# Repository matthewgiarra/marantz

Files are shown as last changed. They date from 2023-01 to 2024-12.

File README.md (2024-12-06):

# marantz
Knockoffs of old Marantz stereos

# Actual content
[P700 Pre-amp board](https://github.com/matthewgiarra/marantz/tree/main/2225/PE01) with schematics, PCB layout, renders, gerber files, and photos of the completed board. 

[Confluence page](https://matthewgiarra.atlassian.net/wiki/spaces/marantz/pages/33577/Gesundheit+Model+82+Stereophonic+Receiver+Requirements) (design concepts, system requirements, etc.)

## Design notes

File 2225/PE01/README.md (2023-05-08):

# Marantz 2225 Pre-Tone Amplifier PE-01 (pre-amp)
## Overview
This project recreates (i.e., knocks off) the [Marantz 2225](https://classicreceivers.com/marantz-2225) pre-tone amplifier (PE-01), as specified in the [Marantz 2225L service manual](https://www.manualslib.com/manual/907153/Marantz-2225l.html), using modern and readily-available components. Our custom board is designed to function as a drop-in replacement for the original device. We [selected components](https://docs.google.com/spreadsheets/d/1S8Fiy-nARGqUnUXXbVScigvOsDpP3ZsTfdl-bGImHVc/edit?usp=sharing) that meet or exceed the specifications from the service manual, which were experimentally verified by measuring values of components sourced from a vintage PE-01. When discrepancies were discovered between the service manual's component specifications and physical measurements of vintage components, we prioritized the physical measurements. The PCB layout was modified as necessary to accommodate the physical dimensions of our chosen components, and uses a four-layer PCB rather than the single layer of the original product. We used KiCad for design, and validated functionality via SPICE simulation prior to manufacturing. Quantitative characterization of the physical prototype is still in progress, but the initial subjective impression is that it sounds pretty good. 

## Components
The bill of materials/components list is [here](https://docs.google.com/spreadsheets/d/1S8Fiy-nARGqUnUXXbVScigvOsDpP3ZsTfdl-bGImHVc/edit?usp=sharing).

## KiCad renders 
2225_PE01_layout
2225_PE01_front_03
2225_PE01_back_01
2225_PE01_front_02

## Prototype board (V1.0, March 2023)
marantz_2225_PE01_tone_board_replica_v1 0

## Original PCB
PE01_front
PE01_back

## Schematic and Layout (from [Marantz 2225L service manual](https://www.manualslib.com/manual/907153/Marantz-2225l.html))
PE01_layout
PE01_schematic

## Notes
- CE21 and CE22 should be 3.3µF, not 33µF as they're listed in the service manual.
- CE23 and CE24 are biopolar capacitors, which the service manual does not appear to indicate. 
- The first prototype board substituted the specified 7.5K resistors RE13 and RE14 with 4.7K 1% components. The reason for the substitution was to mitigate clipping observed at higher volume levels (i.e., lower input attenuation) of aux input from a Macbook headphone jack, which was about 1.5VPP.

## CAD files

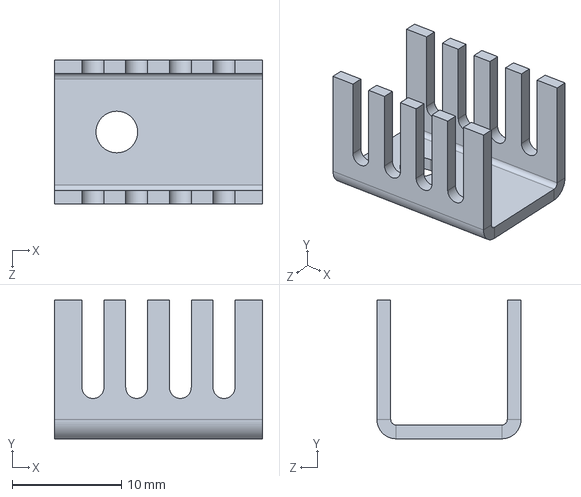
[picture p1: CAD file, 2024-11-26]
2225/P800/3dmodels/heatsink_577202B00000.STEP
19.1 x 12.7 x 13.2 mm

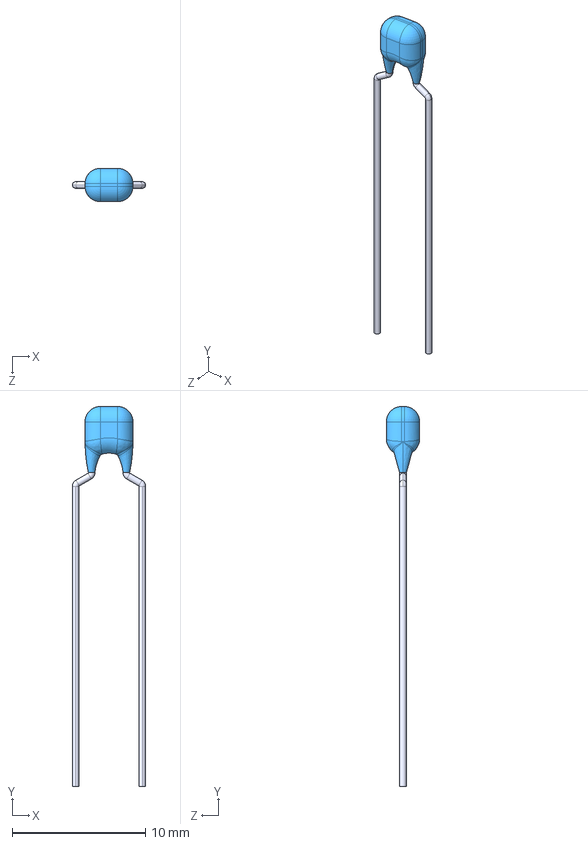
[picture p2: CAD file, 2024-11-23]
2225/P800/3dmodels/cap_ceramic_RCER71H473K0M1H03A.step
5.50 x 28.5 x 2.50 mm

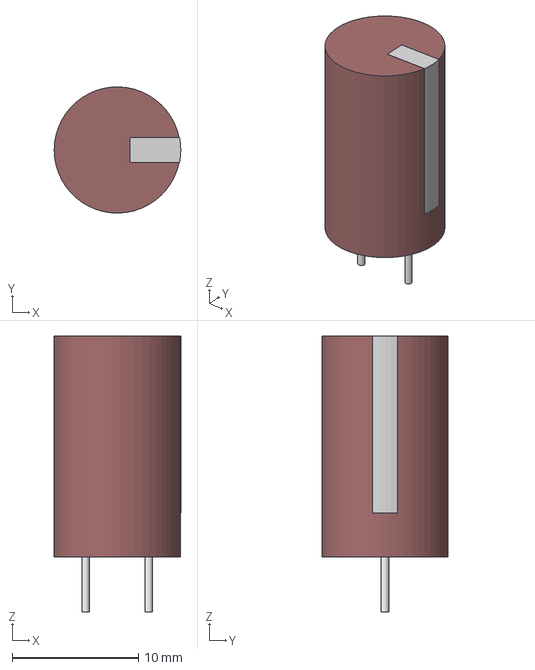
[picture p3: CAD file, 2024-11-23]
2225/P800/3dmodels/cap_electrolytic_UFG1H101MPM1TD.step
10.0 x 10.0 x 21.9 mm

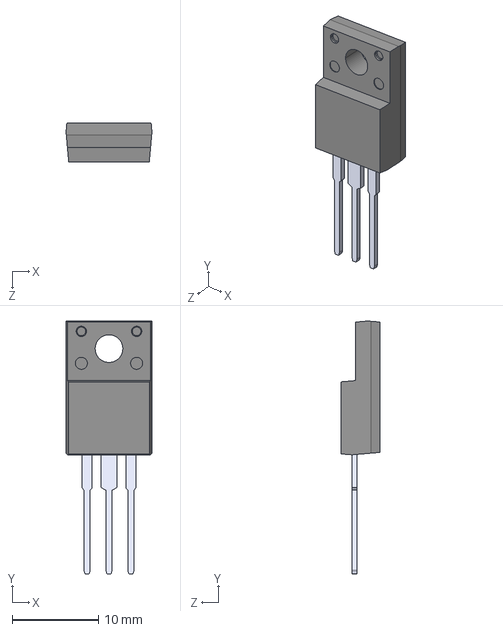
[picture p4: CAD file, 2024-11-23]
2225/P800/3dmodels/TO-220-3_vertical_isolated.step
9.95 x 29.3 x 4.50 mm

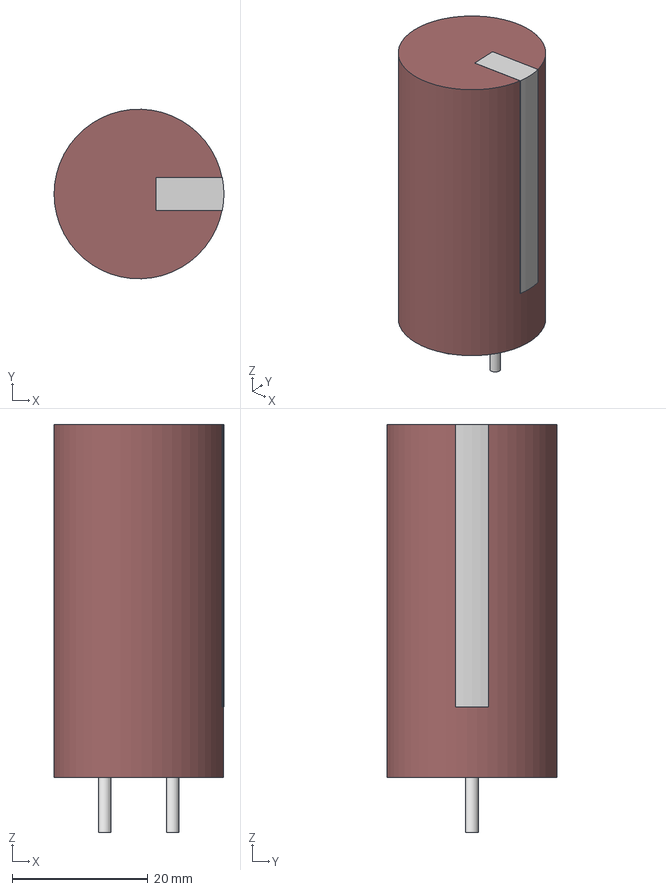
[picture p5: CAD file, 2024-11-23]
2225/P800/3dmodels/cap_electrolytic_A50.step
25.0 x 25.0 x 60.1 mm

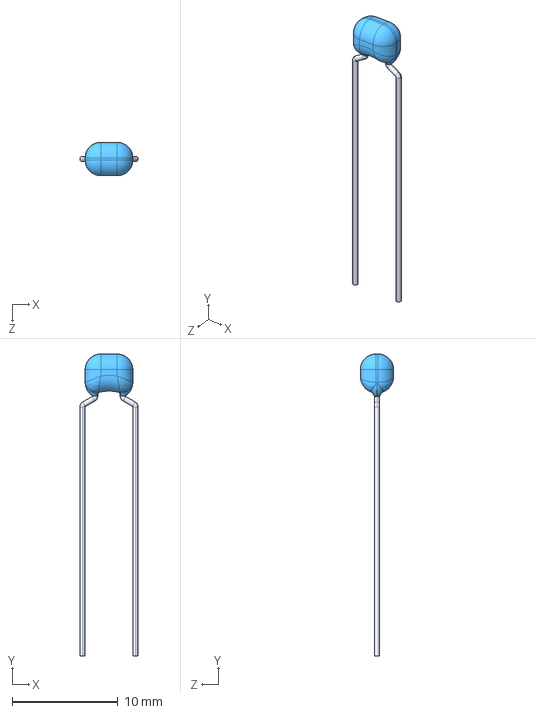
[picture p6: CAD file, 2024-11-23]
2225/P800/3dmodels/cap_ceramic_RDER72H103K1M1H03A.step
5.50 x 28.5 x 3.15 mm

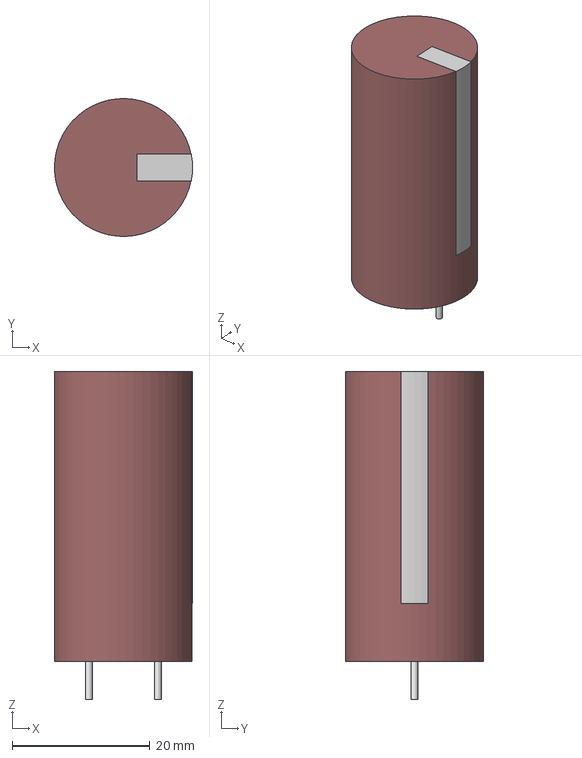
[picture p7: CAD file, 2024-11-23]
2225/P800/3dmodels/cap_electrolytic_UKW1V682MRD.step
20.0 x 20.0 x 47.5 mm

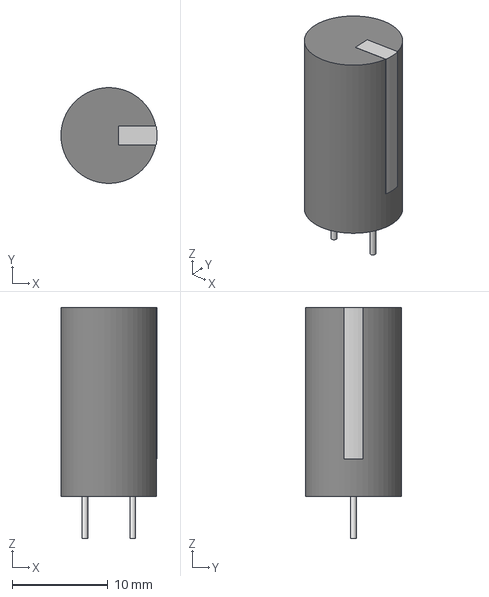
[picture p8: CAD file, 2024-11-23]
2225/P800/3dmodels/cap_electrolytic_UFG1C471MPM1TD.step
10.0 x 10.0 x 24.1 mm

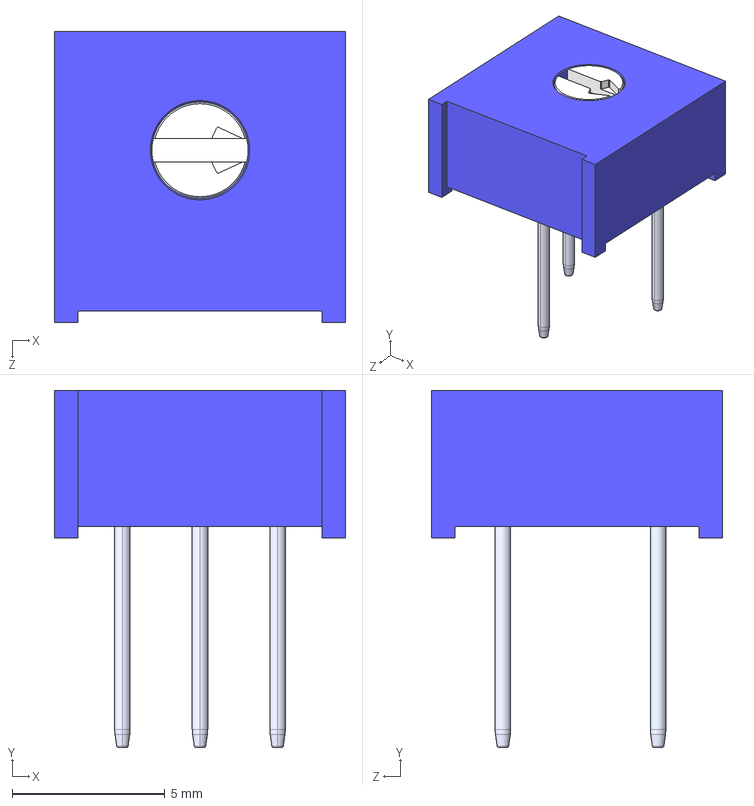
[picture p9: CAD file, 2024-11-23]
2225/P800/3dmodels/pot_3386F-1-502LF.STEP
9.53 x 11.7 x 9.53 mm

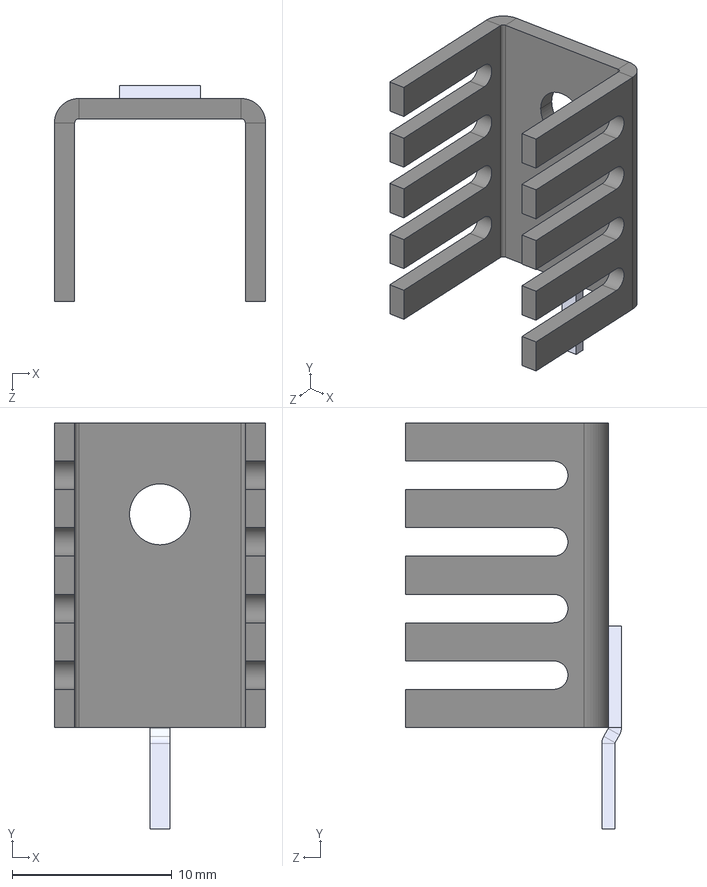
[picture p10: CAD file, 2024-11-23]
2225/P800/3dmodels/heatsink_577202B04000G.step
13.2 x 25.4 x 13.5 mm

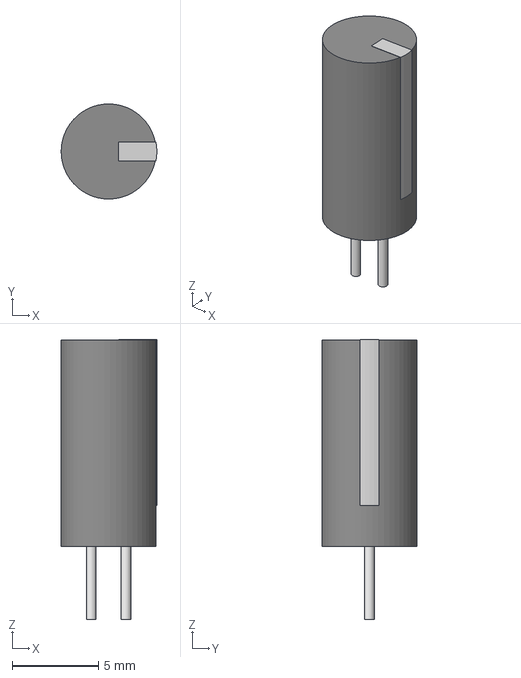
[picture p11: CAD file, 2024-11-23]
2225/P800/3dmodels/cap_electrolytic_panasonic_5X11.step
5.55 x 5.51 x 16.2 mm

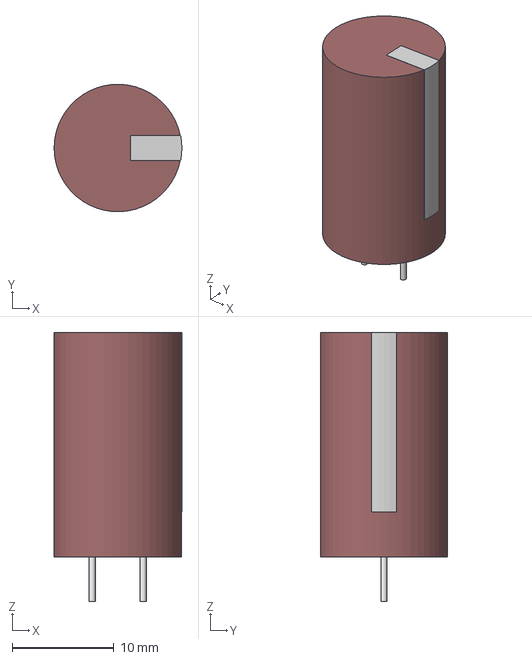
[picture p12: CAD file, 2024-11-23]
2225/P800/3dmodels/cap_electrolytic_UKW1J471MHD1TO.step
12.5 x 12.5 x 26.4 mm

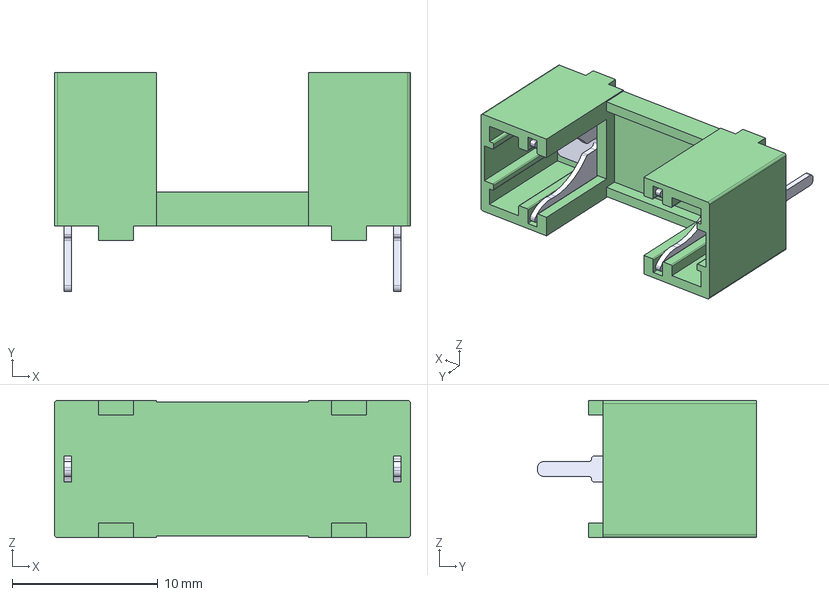
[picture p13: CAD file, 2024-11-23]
2225/P800/3dmodels/fuse_holder_0PTF0078P.step
24.4 x 15.0 x 9.40 mm

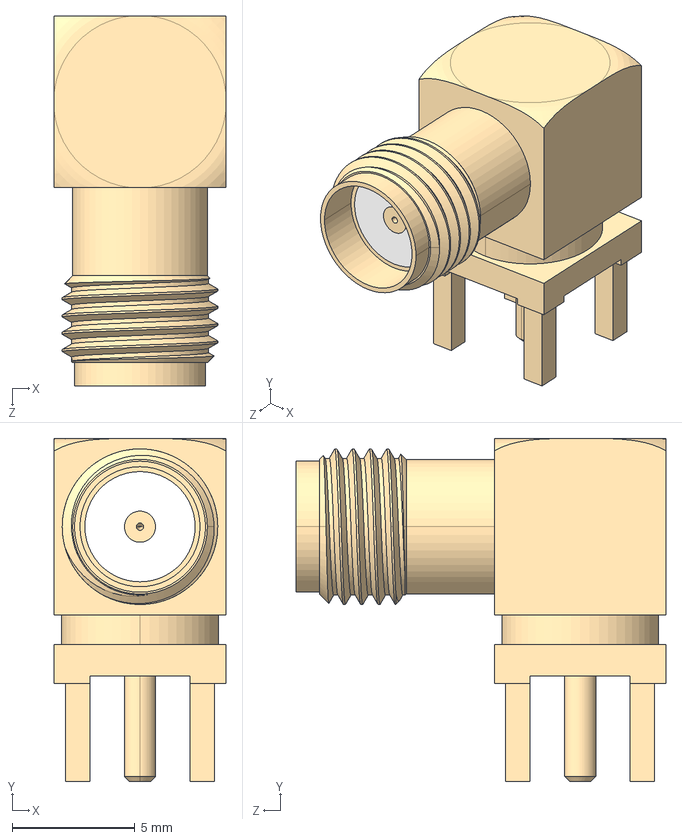
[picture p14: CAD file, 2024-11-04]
2225/P800/3dmodels/sma_connector_RFPC-SMA27-F.step
7.00 x 14.0 x 15.1 mm

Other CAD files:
2225/P800/3dmodels/molex_5pos_connector_395443005.stp
2225/P800/3dmodels/molex_3pos_connector_393570003.stp
2225/P800/3dmodels/molex_2pos_connector_393570002.stp

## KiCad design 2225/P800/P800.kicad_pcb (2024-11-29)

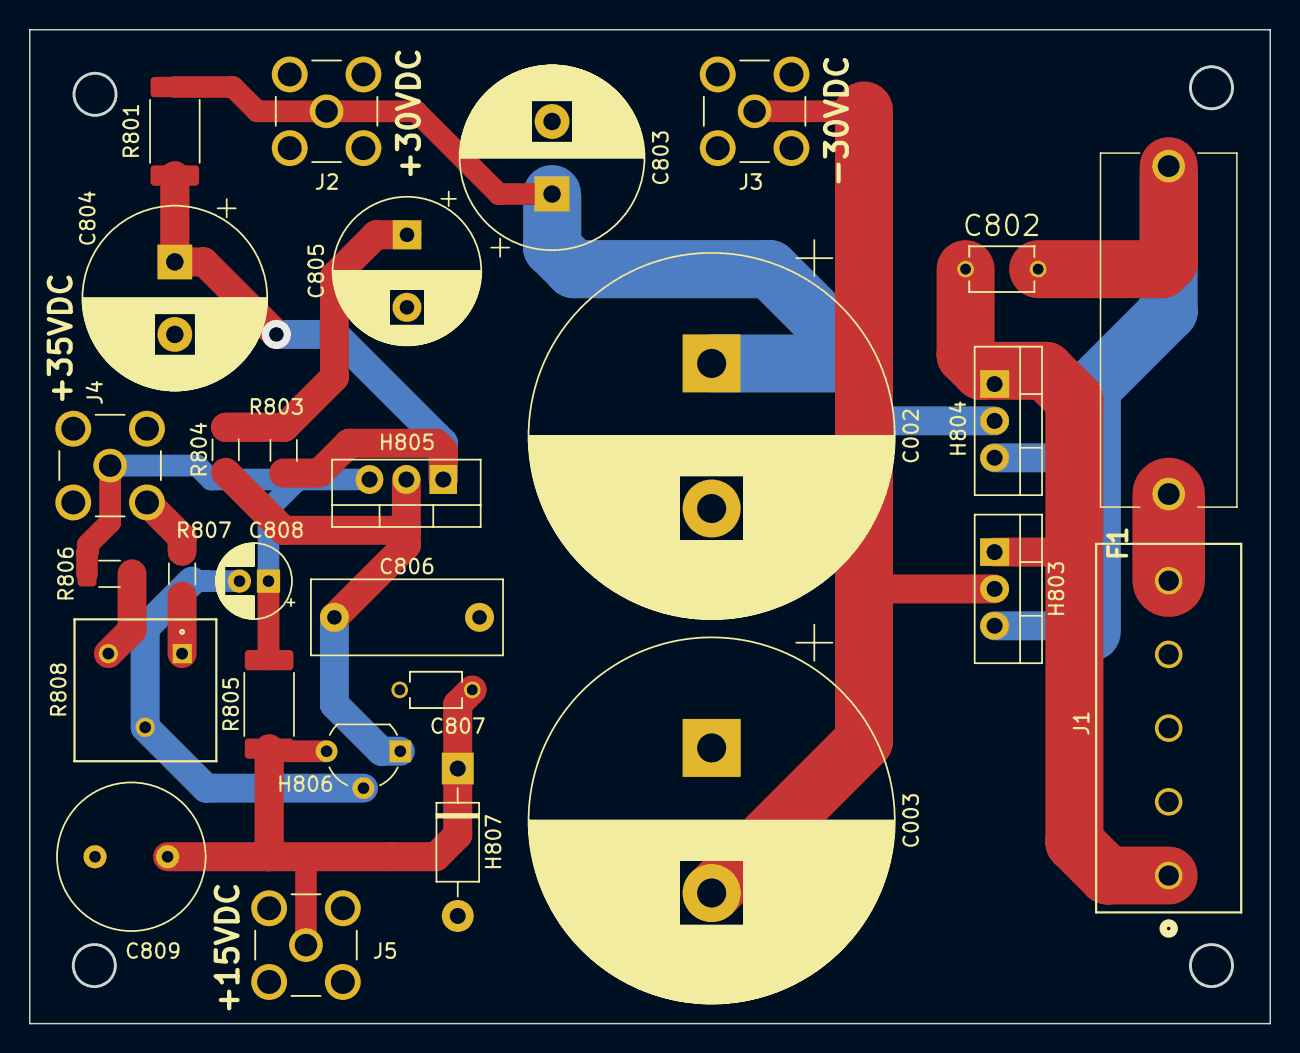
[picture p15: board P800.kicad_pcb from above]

Board: 2 copper layers, 85.5 x 68.5 mm, 29 parts (0 on the bottom side), 14 nets.

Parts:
C002, C003: 6800u; CP_Radial_D25.0mm_P10.00mm_SnapIn
C802: 0.01u; cap_ceramic_RDER72H103K1M1H03A
C803, C804: 470u; CP_Radial_D12.5mm_P5.00mm
C805: 100u; CP_Radial_D10.0mm_P5.00mm
C806: 0.047u; C_Rect_L13.0mm_W5.0mm_P10.00mm_FKS3_FKP3_MKS4
C807: 0.04u; cap_ceramic_RCER71H473K0M1H03A
C808: 3.3u; CP_Radial_D5.0mm_P2.00mm
C809: 470u; C_Radial_D10.0mm_H20.0mm_P5.00mm
F1: Fuse 1A 250V; fuse_holder_0PTF0078P
H803: MBRF10150CTR; TO-220-3_Vertical
H804: MBRF10150CT; TO-220-3_Vertical
H805: TIP41C; TO-220-3_Vertical
H806: KSC2383; TO-92_Wide
H807: 1N4744; D_DO-41_SOD81_P10.16mm_Horizontal
HS1: Heatsink; heatsink_577202B00000G
J1: Screw_Terminal_01x05; molex_5pos_connector_395443005
J2, J3, J4, J5: Conn_Coaxial; sma_connector_RFPC-SMA27-F
R801: 22; R_2512_6332Metric_Pad1.40x3.35mm_HandSolder
R803, R804: 1.5k; R_1206_3216Metric_Pad1.30x1.75mm_HandSolder
R805: 330; R_2512_6332Metric_Pad1.40x3.35mm_HandSolder
R806: 39k; R_1206_3216Metric_Pad1.30x1.75mm_HandSolder
R807: 36k; R_1206_3216Metric_Pad1.30x1.75mm_HandSolder
R808: TRIMPOT 5K; pot_3386F-1-502LF

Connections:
/15VDC_out: C807.1, C809.1, H806.3 (E), H807.1 (K), J5.1 (In), R805.1
/35VDC_out: C808.1, H805.3 (E), J4.1 (In), R805.2, R806.2
/+24VAC: C802.1, F1.2, H803.3, H804.3
/+30VDC_out: C002.1, C803.1, H804.2, J2.1 (In), R801.1
/-24VAC: C802.2, H803.1, H804.1, J1.1
/-30VDC_out: C003.2, H803.2, J3.1 (In)
GND: C002.2, C003.1, C803.2, C804.2, C805.2, C806.2, C807.2, C809.2, H807.2 (A), J1.2, J1.3, J1.4, J2.2 (Ext), J3.2 (Ext), J4.2 (Ext), J5.2 (Ext), R807.1
unnamed: C805.1, R803.1, R804.2
unnamed: C806.1, H805.2 (B), H806.1 (C), R804.1
unnamed: C804.1, H805.1 (C), R801.2, R803.2
unnamed: C808.2, H806.2 (B), R808.2
unnamed: F1.1, J1.5
unnamed: R806.1, R808.3
unnamed: R807.2, R808.1

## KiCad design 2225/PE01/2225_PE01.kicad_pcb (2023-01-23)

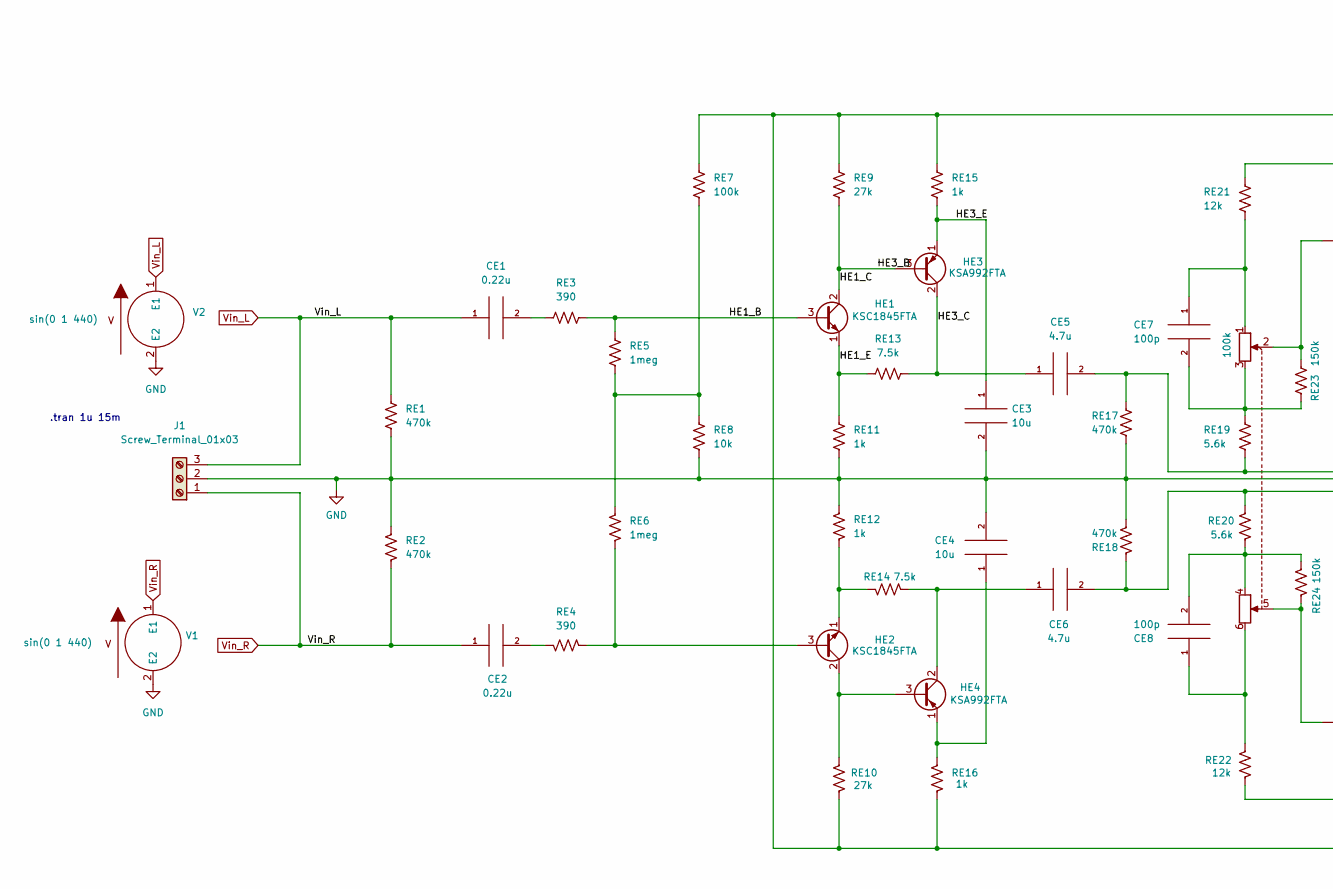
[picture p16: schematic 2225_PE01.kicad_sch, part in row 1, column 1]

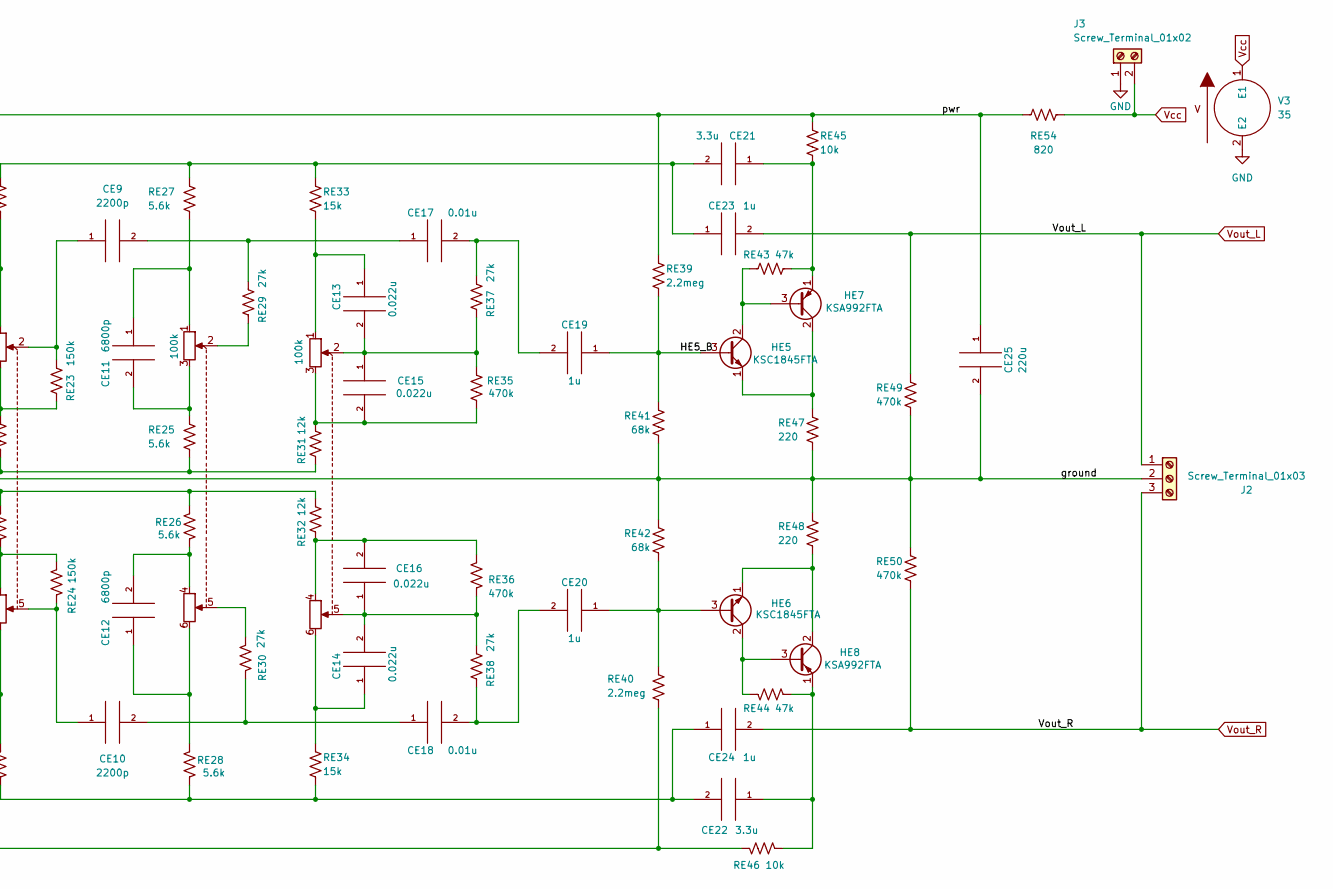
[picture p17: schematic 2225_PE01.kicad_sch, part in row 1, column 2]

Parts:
CE1, CE2: 0.22u; C_Rect_L16.5mm_W4.7mm_P15.00mm_MKT
CE3, CE4: 10u; CP_Radial_D6.3mm_P2.50mm
CE5, CE6: 4.7u; CP_Radial_D5.0mm_P2.50mm
CE7, CE8: 100p; C_Disc_D7.0mm_W2.5mm_P5.00mm
CE9, CE10: 2200p; C_Rect_L7.2mm_W3.5mm_P5.00mm_FKS2_FKP2_MKS2_MKP2
CE11, CE12: 6800p; C_Rect_L7.2mm_W3.5mm_P5.00mm_FKS2_FKP2_MKS2_MKP2
CE13, CE14, CE15, CE16: 0.022u; C_Rect_L10.0mm_W4.0mm_P7.50mm_FKS3_FKP3
CE17, CE18: 0.01u; C_Rect_L9.0mm_W3.2mm_P7.50mm_MKT
CE19, CE20: 1u; CP_Radial_D5.0mm_P2.50mm
CE21, CE22: 3.3u; CP_Radial_D6.3mm_P2.50mm
CE23: 1u; C_Radial_D6.3mm_H11.0mm_P3.50mm
CE24: 1u; C_Radial_D6.3mm_H11.0mm_P2.50mm
CE25: 220u; CP_Radial_D10.0mm_P5.00mm
HE1, HE2, HE5, HE6: KSC1845FTA; TO-92_Inline
HE3, HE4, HE7, HE8: KSA992FTA; TO-92_Inline
J1, J2: Screw_Terminal_01x03; Molex_Eurostyle_39357-0003_1x03_P3.5mm_Horizontal
J3: Screw_Terminal_01x02; Molex_Eurostyle_39357-0002_1x02_P3.5mm_Horizontal
RE1, RE2, RE17, RE18, RE35, RE36, RE49, RE50: 470k; R_Axial_DIN0309_L9.0mm_D3.2mm_P12.70mm_Horizontal
RE3, RE4: 390; R_Axial_DIN0309_L9.0mm_D3.2mm_P12.70mm_Horizontal
RE5, RE6: 1meg; R_Axial_DIN0309_L9.0mm_D3.2mm_P5.08mm_Vertical
RE7: 100k; R_Axial_DIN0309_L9.0mm_D3.2mm_P12.70mm_Horizontal
RE8, RE45, RE46: 10k; R_Axial_DIN0309_L9.0mm_D3.2mm_P12.70mm_Horizontal
RE9, RE10, RE29, RE30, RE37, RE38: 27k; R_Axial_DIN0309_L9.0mm_D3.2mm_P12.70mm_Horizontal
RE11: 1k; R_Axial_DIN0309_L9.0mm_D3.2mm_P20.32mm_Horizontal
RE12, RE15, RE16: 1k; R_Axial_DIN0309_L9.0mm_D3.2mm_P12.70mm_Horizontal
RE13, RE14: 7.5k; R_Axial_DIN0309_L9.0mm_D3.2mm_P12.70mm_Horizontal
RE19, RE20, RE25, RE26, RE27, RE28: 5.6k; R_Axial_DIN0309_L9.0mm_D3.2mm_P12.70mm_Horizontal
RE21, RE22, RE31, RE32: 12k; R_Axial_DIN0309_L9.0mm_D3.2mm_P12.70mm_Horizontal
RE23, RE24: 150k; R_Axial_DIN0309_L9.0mm_D3.2mm_P12.70mm_Horizontal
RE33, RE34: 15k; R_Axial_DIN0309_L9.0mm_D3.2mm_P12.70mm_Horizontal
RE39, RE40: 2.2meg; R_Axial_DIN0309_L9.0mm_D3.2mm_P12.70mm_Horizontal
RE41, RE42: 68k; R_Axial_DIN0309_L9.0mm_D3.2mm_P12.70mm_Horizontal
RE43, RE44: 47k; R_Axial_DIN0309_L9.0mm_D3.2mm_P12.70mm_Horizontal
RE47, RE48: 220; R_Axial_DIN0309_L9.0mm_D3.2mm_P12.70mm_Horizontal
RE51, RE52, RE53: 100k; Potentiometer_Marantz_RM0104005
RE54: 820; R_Axial_DIN0309_L9.0mm_D3.2mm_P12.70mm_Horizontal
V1, V2: 0
V3: 35

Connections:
/HE1_B: HE1.3 (B), RE3.2, RE5.2
/HE1_C: HE1.2 (C), HE3.3 (B), RE9.1
/HE1_E: HE1.1 (E), RE11.2, RE13.1
/HE3_C: CE5.1, HE3.2 (C), RE13.2
/HE3_E: CE3.1, HE3.1 (E), RE15.1
/HE5_B: CE19.1, HE5.3 (B), RE39.1, RE41.2
/pwr: CE25.1, RE7.2, RE9.2, RE10.2, RE15.2, RE16.2, RE39.2, RE40.1, RE45.2, RE46.1, RE54.1
GND: CE3.2, CE4.2, CE25.2, J1.2, J2.2, J3.1, RE1.1, RE2.1, RE8.1, RE11.1, RE12.1, RE17.1, RE18.1, RE41.1, RE42.2, RE47.1, RE48.2, RE49.1, RE50.2, V1.2 (E2), V2.2 (E2), V3.2 (E2)
unnamed: CE1.2, RE3.1
unnamed: CE2.2, RE4.1
unnamed: CE4.1, HE4.1 (E), RE16.1
unnamed: CE5.2, RE17.2, RE19.1, RE25.1, RE31.1
unnamed: CE6.1, HE4.2 (C), RE14.2
unnamed: CE6.2, RE18.2, RE20.1, RE26.1, RE32.2
unnamed: CE7.1, RE21.1, RE51.1
unnamed: CE7.2, RE19.2, RE23.1, RE51.3
unnamed: CE8.1, RE22.1, RE51.6
unnamed: CE8.2, RE20.2, RE24.1, RE51.4
unnamed: CE9.1, RE23.2, RE51.2
unnamed: CE10.1, RE24.2, RE51.5
unnamed: CE10.2, CE18.1, RE30.2
unnamed: CE11.1, RE27.1, RE52.1
unnamed: CE11.2, RE25.2, RE52.3
unnamed: CE12.1, RE28.1, RE52.6
unnamed: CE12.2, RE26.2, RE52.4
unnamed: CE13.1, RE33.1, RE53.1
unnamed: CE13.2, CE15.1, RE35.2, RE37.1, RE53.2
unnamed: CE14.1, RE34.2, RE53.6
unnamed: CE14.2, CE16.1, RE36.2, RE38.2, RE53.5
unnamed: CE15.2, RE31.2, RE35.1, RE53.3
unnamed: CE16.2, RE32.1, RE36.1, RE53.4
unnamed: CE9.2, CE17.1, RE29.2
unnamed: CE17.2, CE19.2, RE37.2
unnamed: CE18.2, CE20.2, RE38.1
unnamed: CE20.1, HE6.3 (B), RE40.2, RE42.1
unnamed: CE21.1, HE7.1 (E), RE43.2, RE45.1
unnamed: CE21.2, CE23.1, RE21.2, RE27.2, RE33.2
unnamed: CE22.1, HE8.1 (E), RE44.2, RE46.2
unnamed: CE22.2, CE24.1, RE22.2, RE28.2, RE34.1
unnamed: HE2.1 (E), RE12.2, RE14.1
unnamed: HE2.2 (C), HE4.3 (B), RE10.1
unnamed: HE2.3 (B), RE4.2, RE6.2
unnamed: HE5.1 (E), HE7.2 (C), RE47.2
unnamed: HE5.2 (C), HE7.3 (B), RE43.1
unnamed: HE6.1 (E), HE8.2 (C), RE48.1
unnamed: HE6.2 (C), HE8.3 (B), RE44.1
unnamed: RE5.1, RE6.1, RE7.1, RE8.2
unnamed: RE29.1, RE52.2
unnamed: RE30.1, RE52.5
Vcc: J3.2, RE54.2, V3.1 (E1)
Vin_L: CE1.1, J1.3, RE1.2, V2.1 (E1)
Vin_R: CE2.1, J1.1, RE2.2, V1.1 (E1)
Vout_L: CE23.2, J2.1, RE49.2
Vout_R: CE24.2, J2.3, RE50.1

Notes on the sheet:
.tran 1u 15m

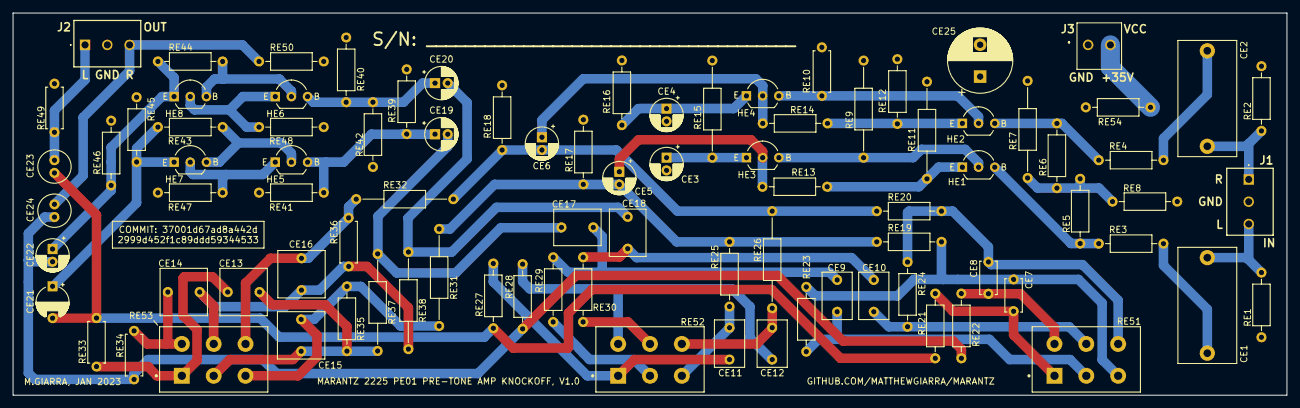
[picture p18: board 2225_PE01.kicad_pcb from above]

Board: 4 copper layers, 200.0 x 60.0 mm, 90 parts (0 on the bottom side), 54 nets.

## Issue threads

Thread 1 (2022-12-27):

Replace pot footprint with Bourns part

matthewgiarra, 2022-12-27:
Current footprint reflects the original pot, which is no longer widely available.

Replace with a readily-available component, like Bourns PDB18 series 17mm pot.

Data sheet with drawing is here: https://www.bourns.com/docs/Product-Datasheets/PDB18.pdf

matthewgiarra, 2023-01-16:
Merged d9744e7c0ee91cb9f287f0c178af6e282369b3a9

Closed 2023-01-16.

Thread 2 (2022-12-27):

Change pot pins to match Bourns PDB18 series

matthewgiarra, 2022-12-27:
Pot pin numbers were chosen based on the service manual schematic or something.

Change pot pin numbers to reflect the Bourns series PDB18 pot that we will use.

Datsheet is here: https://www.bourns.com/docs/Product-Datasheets/PDB18.pdf

matthewgiarra, 2023-01-16:
Merged d9744e7c0ee91cb9f287f0c178af6e282369b3a9

Closed 2023-01-16.

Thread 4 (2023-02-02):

CE21 footprint pads too far apart

matthewgiarra, 2023-02-02:
I had modified the CE21 footprint to make space to route a trace between its pads. When I updated the board design from 1 to 4 layers, that trace no longer needed to route between the CE21 pads, but I forgot to update its footprint. The reason it matters is that the component won’t sit flush with the board with the wider pad spacing.

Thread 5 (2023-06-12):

Update PE01 potentiometer 3D models to Bourns official files

matthewgiarra, 2023-06-12:
Currently using a 3D CAD model of unknown origin for the tone board (PE01) pots (RE51, RE52, RE53). Use the [Bourns official CAD models](https://www.bourns.com/resources/design-tools/design-files) instead.

[Here](https://www.bourns.com/resources/design-tools/engineering-files-list?Folder=PDB18) is a list of the Bourns CAD files for PDB-18x series pots

Of these, you want [PDB182-k2220k](https://www.bourns.com/engineering/PDB18/pdb182-k2220k.stp).

matthewgiarra, 2023-06-12:
After downloading the 3D models, you can view them in a browser using [Autodesk Viewer](https://viewer.autodesk.com/designviews).

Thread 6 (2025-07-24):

Redesign PE01 board

matthewgiarra, 2025-07-24:
1. Incorporate volume knob with loudness circuit
2. Replace soldered-to-board pots with new connections (molex JST PH-series) to stand-alone breakout boards.
3. Isolate power ground from signal ground paths
4. Add terminals to signal ground & power ground to P800

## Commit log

2022-10-23 Initial commit of KiCad files. 2225 PE01 schematic drafted and PCB component initial placement done.
    [2225_PE01.kicad_pcb, 2225_PE01.kicad_sch]
2022-10-23 Added rough board outline to PCB (dimensions are wrong).
    [2225_PE01.kicad_pcb]
2022-11-10 Set PCB component positions to match holes on donor board
    [2225_PE01.kicad_pcb, 2225_PE01.kicad_sch]
2022-11-10 Fixed CE1, which was upside down on pcb layout
    [2225_PE01.kicad_pcb]
2022-11-10 Fixed short circuit across RE8. Added traces. Still need ground plane.
    [2225_PE01.kicad_pcb, 2225_PE01.kicad_sch]
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2022-11-10 Updated footprint symbols types to match real board (squiggly resistors, etc). Also updated annotations for RE51, RE52, RE53
    [2225_PE01.kicad_pcb, 2225_PE01.kicad_sch]
2022-11-10 Made more PCB footprints to match schematic symbols. Also aligned component text in PCB silkscreen.
    [2225_PE01.kicad_pcb]
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2022-11-10 Changed footprints of RE5 and RE6 from vertical resistors to horizontal
    [2225_PE01.kicad_pcb]
2022-11-10 Changed transistor footprints to common packaging spec. Also fixed some trace intersections.
    [2225_PE01.kicad_pcb]
2022-11-10 Changed some capacitor footprints to match real components
    [2225_PE01.kicad_pcb]
2022-11-10 Updated footprints of CE9 - CE12. Changed some trace widths to 0.5mm
    [2225_PE01.kicad_pcb]
2022-11-10 Changed footprint of CE13 and CE14 to real WIMA caps.
    [2225_PE01.kicad_pcb]
2022-11-10 Updated capacitor footprints to represent available components
    [2225_PE01.kicad_pcb]
2022-11-10 Cleaned up traces and made most of them 1mm
    [2225_PE01.kicad_pcb]
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2022-11-10 Repositioned some components so that ground plane actually tied grounds together
    [2225_PE01.kicad_pcb]
2022-11-10 Moved some traces around to make room around components
    [2225_PE01.kicad_pcb]
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2022-11-10 Rerouted traces and moved components to tie together ground plane
    [2225_PE01.kicad_pcb]
2022-11-10 Rerouted components and traces to consolidate ground plane
    [2225_PE01.kicad_pcb]
2022-11-10 Widened some choke points on the ground plane
    [2225_PE01.kicad_pcb]
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2022-11-15 Updated footprints of resitors and caps to match final component selections
    [2225_PE01.kicad_pcb]
2022-11-15 Moved components and updated fooprints to mitigate design rules checker warnings
    [2225_PE01.kicad_pcb]
2022-12-27 Got spice simulation working. Put all component libraries in PE01.lib
    [2225_PE01.kicad_sch]
2023-01-03 Changed and re-positioned pot footprints. Left traces as-is, so this commit is a WIP.
    [2225_PE01.kicad_pcb]
2023-01-16 Made board 4 layers and re-routed all the traces.
    [2225_PE01.kicad_pcb, 2225_PE01.kicad_sch]
2023-01-17 Updated design rules and some footprints to match EasyEDA requirements.
    [2225_PE01.kicad_pcb]
2023-01-17 Cropped footprints that overlapped board edge; moved some text.
    [2225_PE01.kicad_pcb]
2023-01-17 Added textbox with hash of previous commit to PCB silkscreen
    [2225_PE01.kicad_pcb]
2023-01-18 Added silkscreen text to label terminal block connections; moved components to accommodate text.
    [2225_PE01.kicad_pcb]
2023-01-23 Updated names of front and back copper layers to not include (L) and (R)
    [2225_PE01.kicad_pcb]
2023-01-23 Updated 2225 PE01 silk screen to reflect board as-released for mfg. Added gerberfiles that were released to manufacturer (JLCPCB order Y3-5424344A).
    [2225_PE01-B_Cu.gbr, 2225_PE01-B_Mask.gbr, 2225_PE01-Edge_Cuts.gbr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]
2023-05-05 Disabled terminal blocks in spice sim of 2225 PE01 because there was no spice model defined for them and the sim wouldnt run
    [2225_PE01.kicad_sch]
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2023-06-12 Added model files for Zener diode, transistors, and trim pot
    [P800.kicad_sch]
2023-06-13 Created diode bridge components (P800 H801:H804) in project-specific symbol library; updated schematic to include H803 & H804
    [P800.kicad_sch]
2023-06-15 Added model file (subckt) for diode bridges P800 H803 & H804
    [P800.kicad_sch]
2023-06-15 Resolved spice not finding diode model by adding D prefix to model name in D1N4744A.lib
    [P800.kicad_sch]
2023-06-21 Changed feedback transistor P800/H806 to KSC2373; adjusted values of voltage divider in feedback circuit of P800
    [P800.kicad_sch]
2023-07-17 Replaced global labels with hierarchical labels, and removed sources and loads, in 2225_PE01.kicad_sch (in prep. for integrating into multi-sheet schematic)
    [2225_PE01.kicad_sch]
2023-07-17 Consolidated spice model files (.lib) in models directory. Specified spice paths relative to {KIPRJMOD} env variable.
    [2225_PE01.kicad_sch, P800.kicad_sch]
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2023-11-01 Connected transformer to P800 in 2225.kicad_sch; changed transformer model resistances in 2225.lib
    [2225.kicad_sch, P800.kicad_sch]
2023-11-01 Connected P800 (DC supply) to PE01 tone board, audio source to PE01, and PE01 to dummy P700 main amplifier. Changed some hierarchical label names in multiple schematics.
    [2225.kicad_sch, 2225_PE01.kicad_sch, P700.kicad_pcb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]
2023-11-01 Added dummy power inputs to P700 block in 2225.kicad_sch (system block diagram)
    [2225.kicad_sch, P700.kicad_sch, P800.kicad_sch]
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2023-11-09 Committing some changes to 2225_PE01.kicad_sch, but I dont really know why the file changed.
    [2225_PE01.kicad_sch]
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2024-10-03 Aligned 2225/P800 schematic elements to grid so ERC would run without warnings. Deconflicted net names. Fixed warning about GND having been modified in PWR library.
    [P800.kicad_sch]
2024-10-03 Made and populated 2225/P800/3dmodels and libs. Created project footprint library for 2225/P800. Added molex connector foorptints to 2225/P800 library.
    [P800.kicad_sch, molex_2pos_connector_393570002.stp, molex_3pos_connector_393570003.stp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]
2024-11-04 Changed molex block connectors for all VDC_out to SMA right angle THT. Aligned schematic to 50.0 mil grid to fix electrical rules checker warnings.
    [P800.kicad_sch, RFPC-SMA27-F.step]
2024-11-23 Added footprints and 3D models for all components; assigned footprints to all components; populated PCB file with all footprints
    [P800.kicad_pcb, P800.kicad_sch, TO-220-3_vertical_isolated.step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]
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2024-11-28 Replaced custom capacitor footprints with kicad standard footprints
    [P800.kicad_pcb, P800.kicad_sch]
2024-11-28 Replaced star ground pattern with single ground plane
    [P800.kicad_pcb]
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
